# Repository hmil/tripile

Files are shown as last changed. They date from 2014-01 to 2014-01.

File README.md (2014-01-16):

# Trieur de piles 

Ce repo contient tout le nécessaire à la réalisation du trieur de pile vu au concours Innovez 
(si vous ne savez pas de quoi il s'agit, vous vous êtes probablement perdu sur github).
Vous trouverez un assemblage solidworks de la machine, une sketch fritzing et une sketch arduino.
J'ai créé ce repo à partir du dossier que j'ai retrouvé sur mon disque suite à des demandes. Si vous assemblez
tout comme montré, il se peut que celà ne marche pas car j'ai du effectuer des modifications sur la partie électronique.

tl;dr: Le code arduino fonctionne, l'assemblage solidworks est fidèle mais le circuit électronique est probablement buggé.

Enjoy

(c) Hadrien Milano 2013,
La license [beerware](http://fr.wikipedia.org/wiki/Beerware) s'applique à tout le repo.

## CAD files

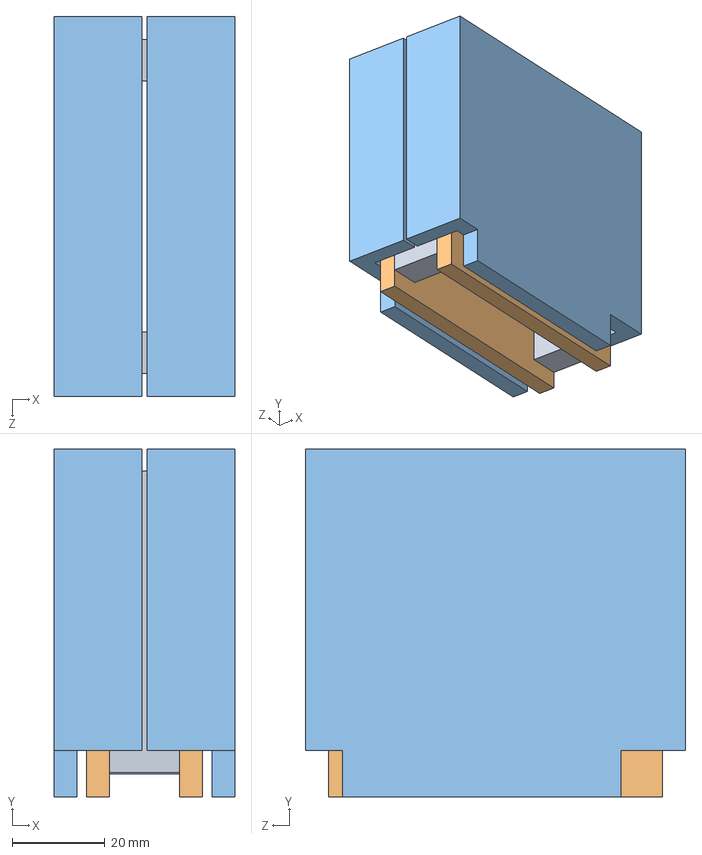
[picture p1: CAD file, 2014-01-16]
solidworks/reserv+recept_rangement.SLDASM
39.0 x 75.0 x 82.0 mm
entretoise x 2
paroi_reservoir x 2
receptacle x 2

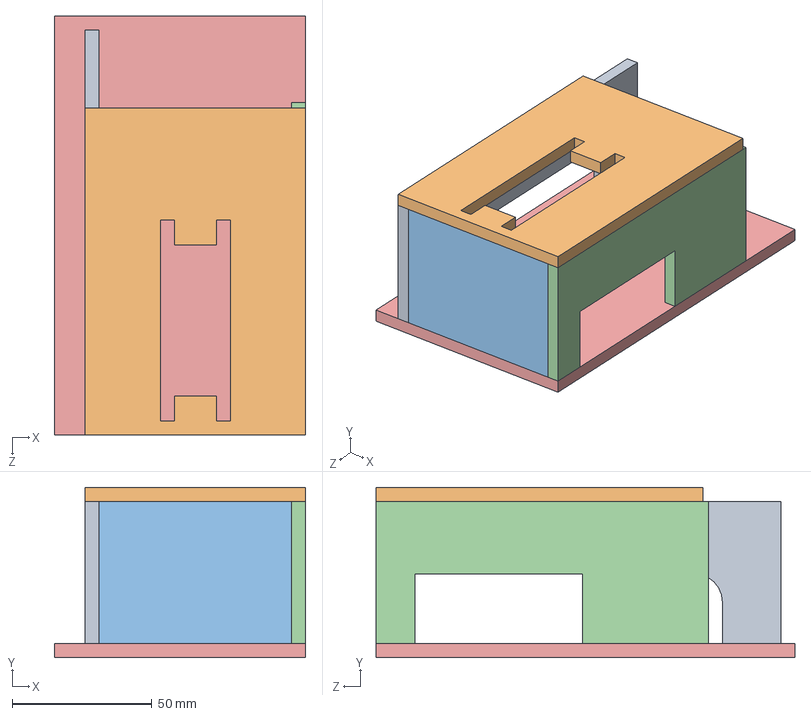
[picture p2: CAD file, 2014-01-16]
solidworks/carter.SLDASM
90.0 x 61.0 x 150.0 mm
top
front
side2
side
base

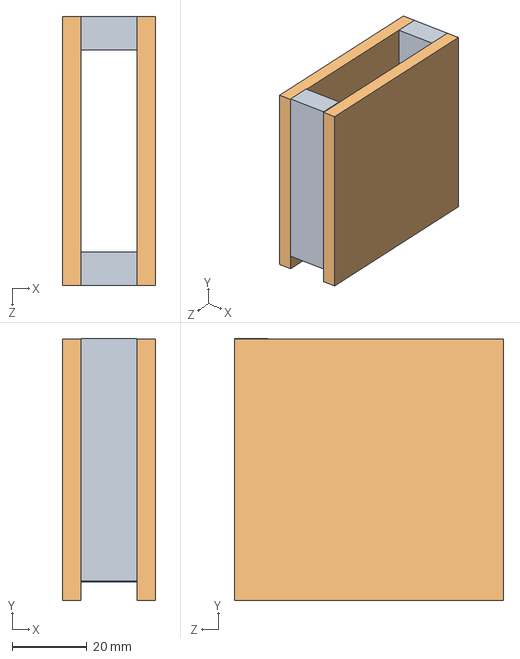
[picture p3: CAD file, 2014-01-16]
solidworks/reservoir.SLDASM
25.0 x 70.2 x 72.0 mm
entretoise x 2
paroi_reservoir x 2

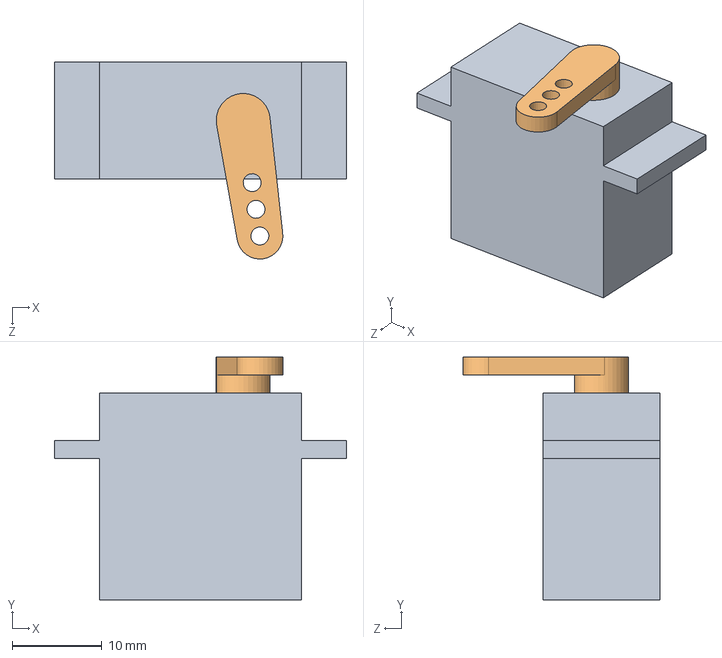
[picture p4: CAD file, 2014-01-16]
solidworks/servo2.SLDASM
32.5 x 27.0 x 21.9 mm
servo2
bras_servo2

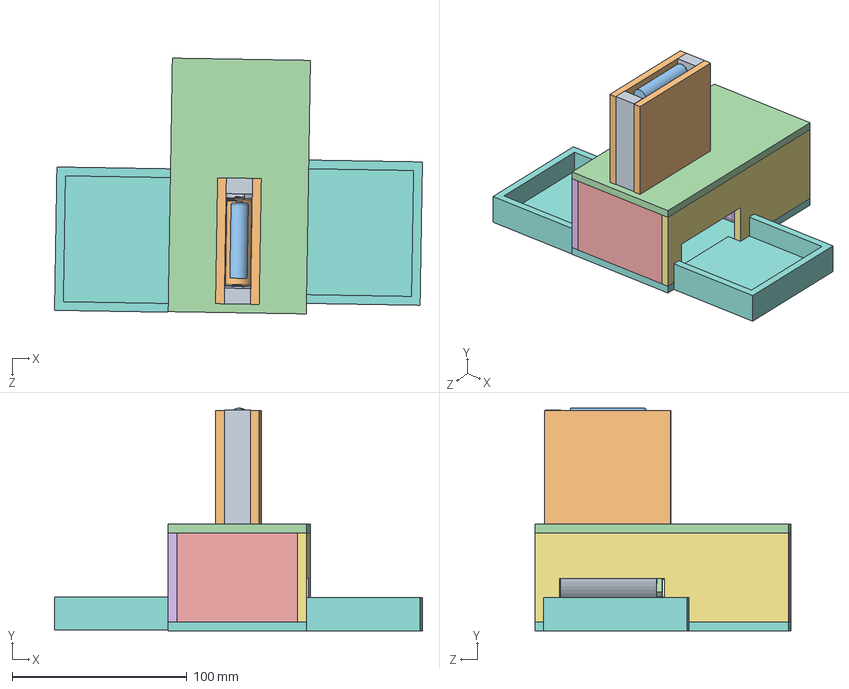
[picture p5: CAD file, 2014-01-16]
solidworks/tripile+2ke.SLDASM
210.4 x 127.4 x 146.3 mm
distributeur
AA Battery x 3
AAA Battery x 4
top
front x 2
side2
side
base
entretoise x 2
paroi_reservoir x 2
support_distrib x 2
servo
support_servo
Battery 9V
traverse x 2
receptacle x 2
servo2
bras_servo2
capot

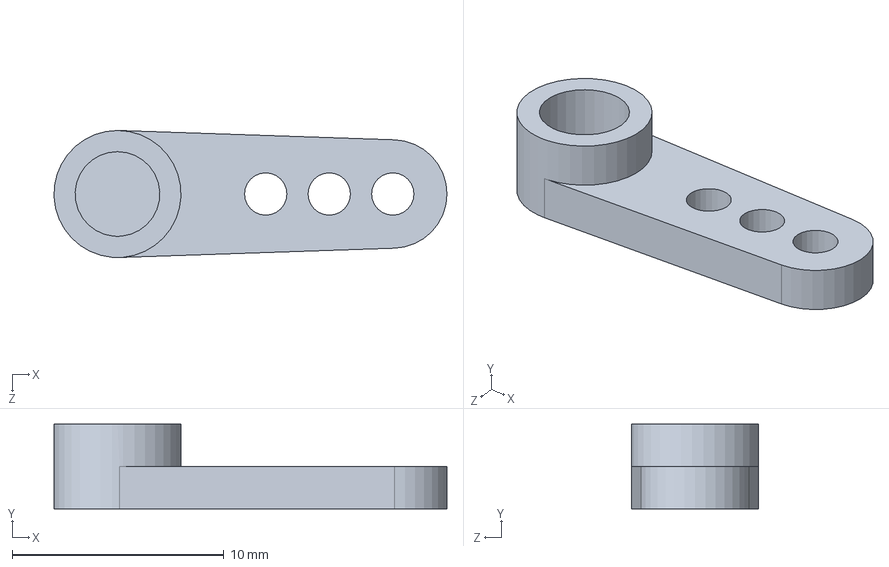
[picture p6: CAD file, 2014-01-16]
solidworks/bras_servo2.SLDPRT
18.6 x 4.00 x 6.00 mm

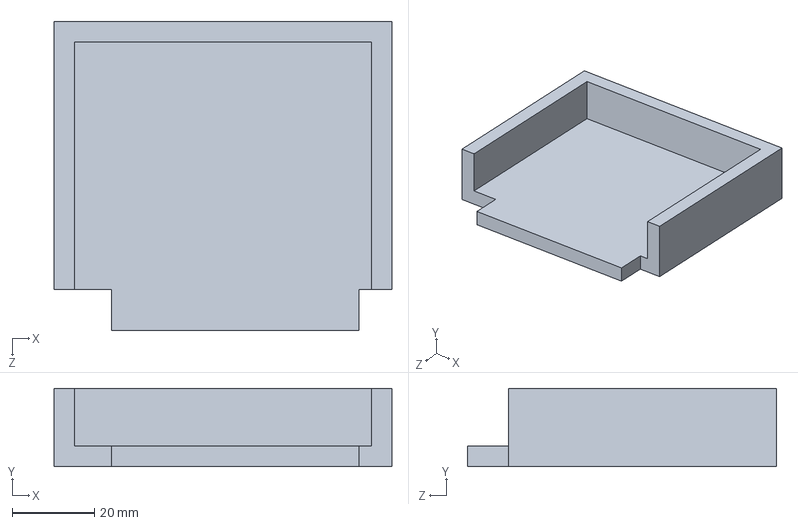
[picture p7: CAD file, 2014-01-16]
solidworks/receptacle.SLDPRT
82.0 x 19.0 x 75.0 mm

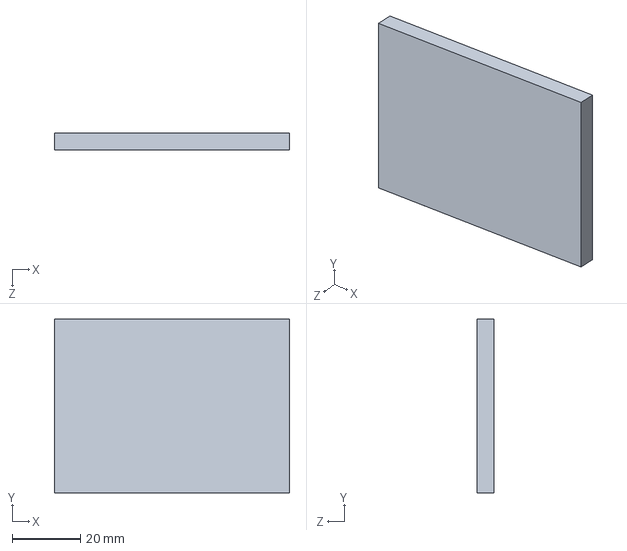
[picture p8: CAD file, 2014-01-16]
solidworks/front.SLDPRT
69.0 x 51.0 x 5.00 mm

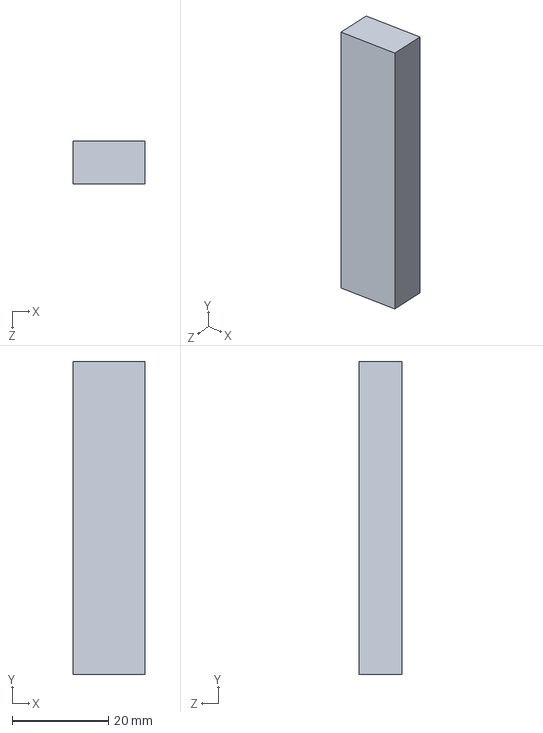
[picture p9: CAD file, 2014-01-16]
solidworks/entretoise.SLDPRT
15.0 x 65.0 x 9.00 mm

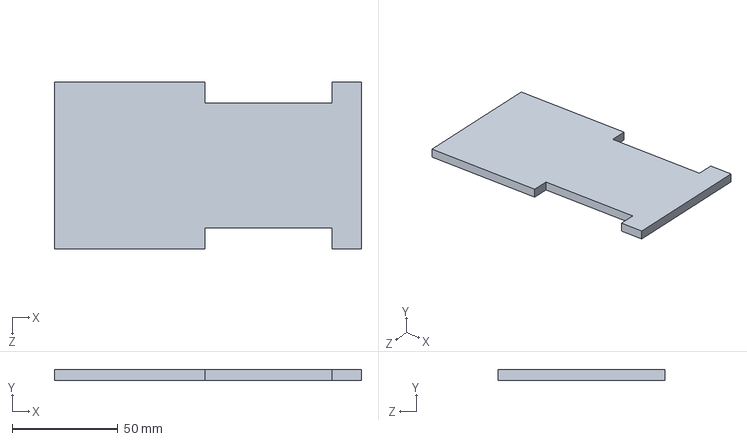
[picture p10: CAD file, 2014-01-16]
solidworks/base.SLDPRT
145.0 x 5.00 x 79.0 mm

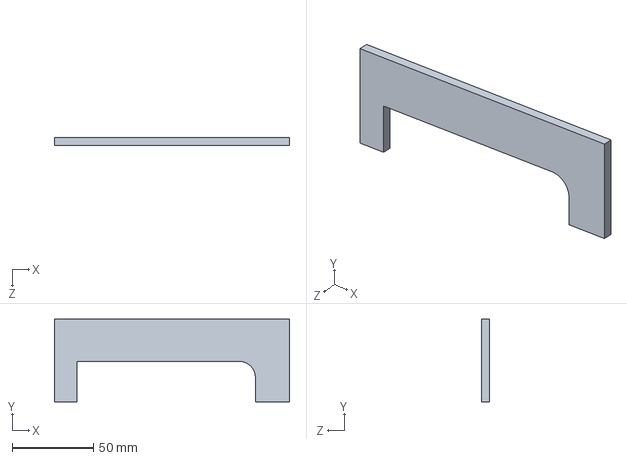
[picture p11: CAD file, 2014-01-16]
solidworks/side2.SLDPRT
145.0 x 51.0 x 5.00 mm

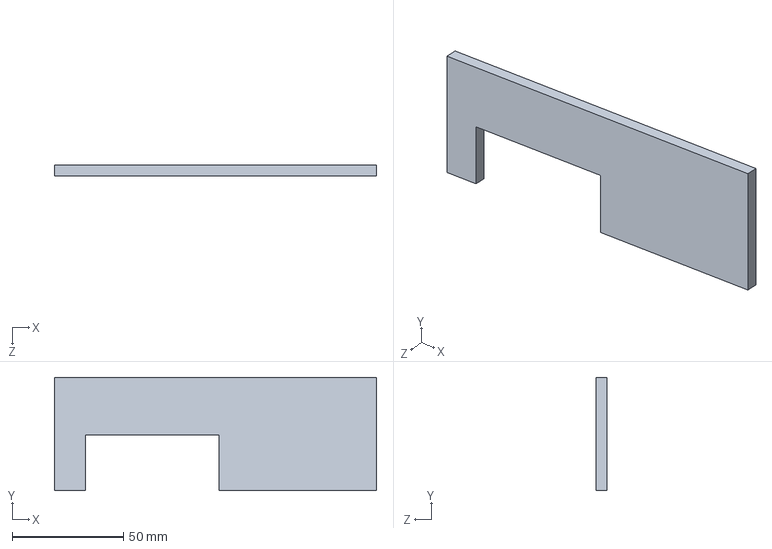
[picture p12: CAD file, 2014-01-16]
solidworks/side.SLDPRT
145.0 x 51.0 x 5.00 mm

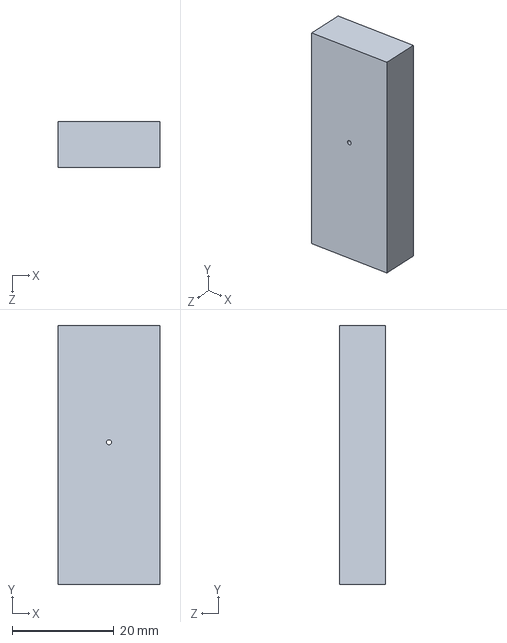
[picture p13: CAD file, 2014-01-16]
solidworks/support_distrib.SLDPRT
20.0 x 51.0 x 9.00 mm

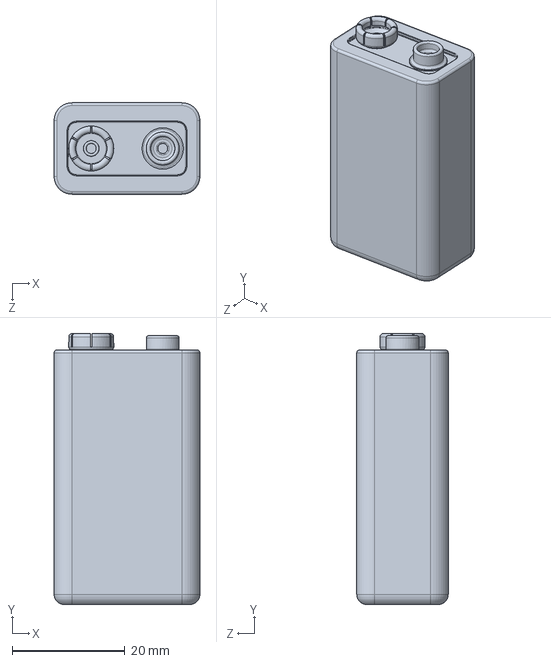
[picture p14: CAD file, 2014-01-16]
solidworks/Battery 9V.SLDPRT
25.9 x 48.1 x 16.3 mm

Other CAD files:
solidworks/support_servo.SLDPRT
solidworks/AA Battery.SLDPRT
solidworks/AAA Battery.SLDPRT
solidworks/renfort.SLDPRT
solidworks/capot.SLDPRT
solidworks/carter.SLDPRT
solidworks/distributeur.SLDPRT
solidworks/paroi_reservoir.SLDPRT
solidworks/servo.SLDPRT
solidworks/servo2.SLDPRT
solidworks/top.SLDPRT
solidworks/traverse.SLDPRT

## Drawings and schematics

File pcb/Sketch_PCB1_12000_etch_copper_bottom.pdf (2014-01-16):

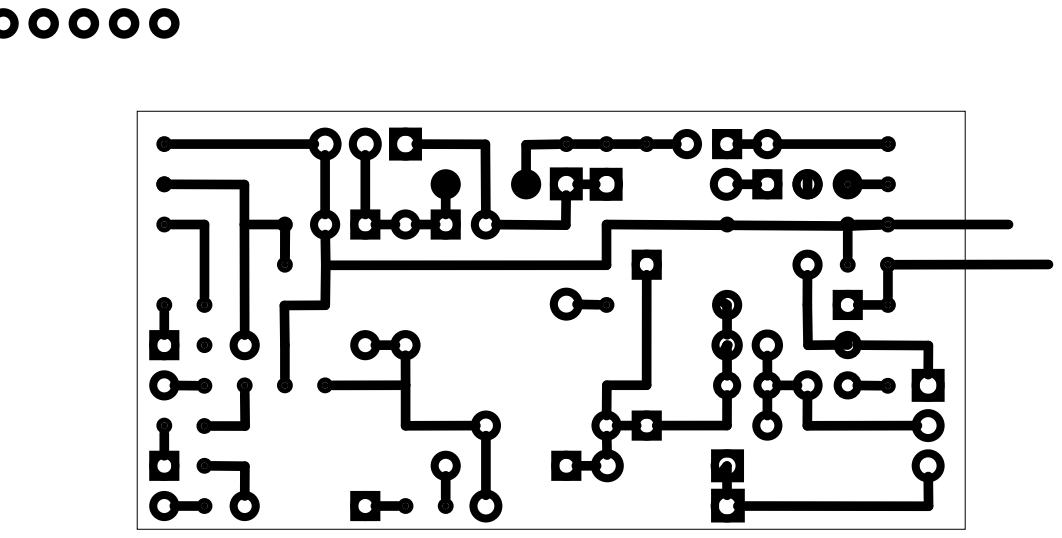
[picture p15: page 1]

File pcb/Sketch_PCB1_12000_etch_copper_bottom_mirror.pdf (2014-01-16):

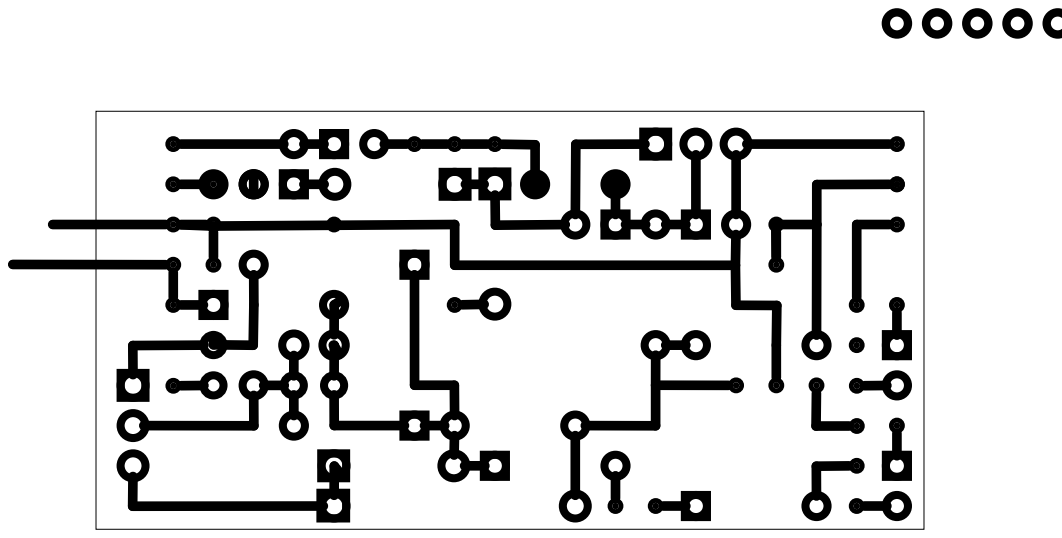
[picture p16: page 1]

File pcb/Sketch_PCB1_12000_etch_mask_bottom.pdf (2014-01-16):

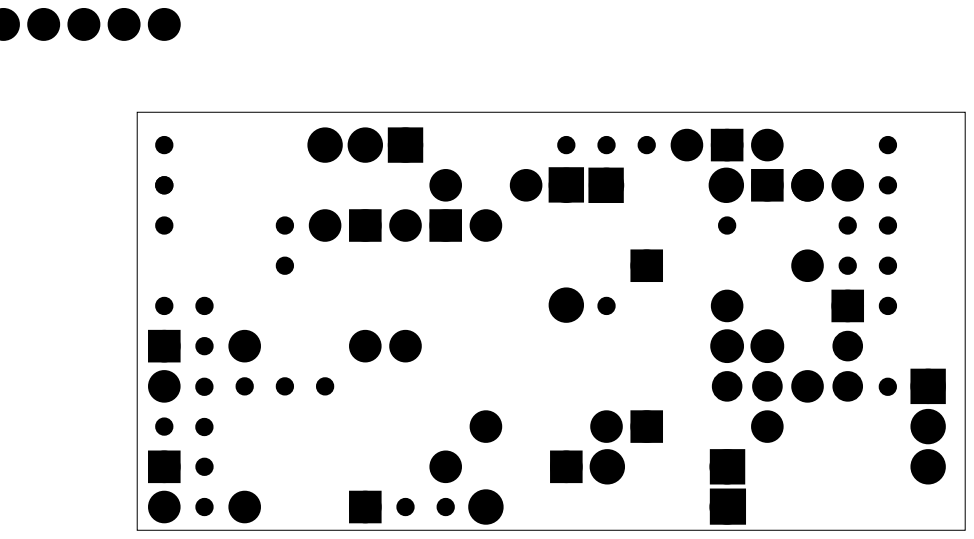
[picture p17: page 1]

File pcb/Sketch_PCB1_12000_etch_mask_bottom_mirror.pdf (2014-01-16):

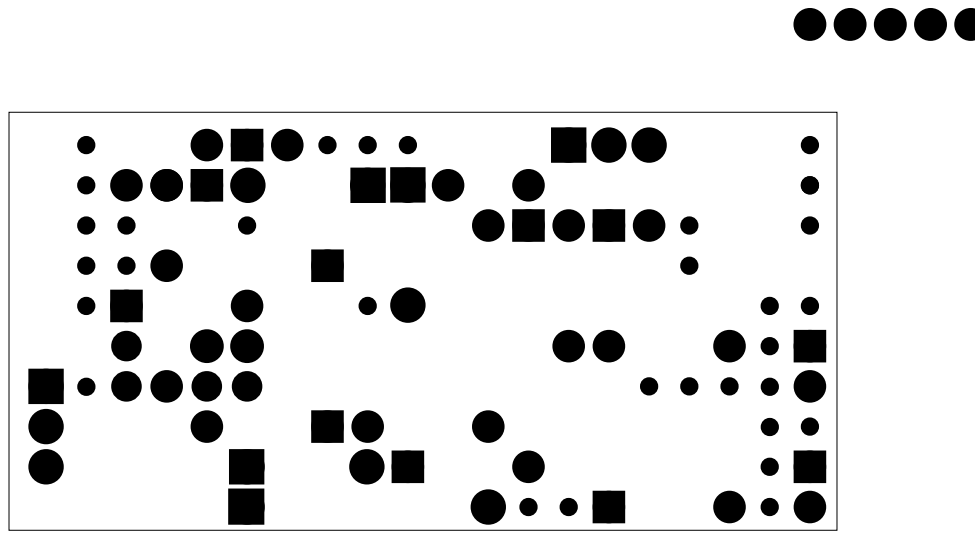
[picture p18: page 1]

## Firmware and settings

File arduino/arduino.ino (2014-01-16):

#include <robopoly.h>
#include <Servo.h>

#define LOW_BATT_VAL            720

#define SONDE_RETRACTED         67
#define SONDE_DEPLOYED_BIG      140
#define SONDE_DEPLOYED_LITTLE   170

#define DISTRIB_MIDDLE          78
#define DISTRIB_LOW             5
#define DISTRIB_HIGH            180

#define DISTRIBUTION_DELAY      700
#define SONDE_DEPLOYMENT_DELAY  500
#define NOISE_THRESHOLD         50
#define PILE_MINIMAL_TENSION    220

//En dessous de cette valeur, l'objet testé est considéré comme un accu
#define ACCU_THRESHOLD          270
/*  Ces valeurs sont comparées aux tensions mesurées en décharge
  hypothèses : 
  - accu : U = 1.2V, r ~= 0.02ohm
  - pile : U = 1.5V, r ~= 1ohm
  
  avec une certaine marge de manoeuvre car ces résultats théoriques 
  peuvent facilement faire passer une pile chargée pour déchargée
  */
#define PILE_LOADED             100
#define ACCU_LOADED             90


//Macro permettant de finaliser un test  
#define FINISH_TEST(success)       \
  servoOneShot(sonde, SONDE_RETRACTED, SONDE_DEPLOYMENT_DELAY);    \
  *result = success;               \
  return true; 

int pilePin = 0;
int batteryPin = 1;

int cptPin = 15;

unsigned char sonde = 5;

unsigned char distrib = 7;

int triggerPin = 13;

int buttonPin = 30;
bool buttonDown = false;

int lowBattLed = 26;
int okLed = 28;
int nokLed = 27;

void checkBattery(){
  int level = analogRead(batteryPin);
  if(level < LOW_BATT_VAL){
    digitalWrite(lowBattLed, true);
  }
}

//Deplace le servo a la position voulue puis le déconnecte (fonction bloquante)
void servoOneShot(unsigned char id, unsigned char angle, int time){
  setServo(id, angle);
  delay(time);
  unsetServo(id);
}

void setup(){
  Serial.begin(9600);
  pinMode(pilePin, INPUT);
  pinMode(batteryPin, INPUT);
  pinMode(triggerPin, OUTPUT);
  pinMode(buttonPin, INPUT);
  pinMode(cptPin, INPUT);
  digitalWrite(triggerPin, LOW);
  
  pinMode(okLed, OUTPUT);
  pinMode(nokLed, OUTPUT);
  pinMode(lowBattLed, OUTPUT);
  
  digitalWrite(okLed, LOW);
  digitalWrite(nokLed, LOW);
  digitalWrite(lowBattLed, LOW);

  servoOneShot(sonde, SONDE_RETRACTED, SONDE_DEPLOYMENT_DELAY);

  servoOneShot(distrib, DISTRIB_MIDDLE, DISTRIBUTION_DELAY);
  
  //On attend que les servo aient fini de tourner pour faire le test de batterie
  delay(200);
  checkBattery();
}

void onPileOk(){
  Serial.println("Pile chargée");
  digitalWrite(okLed, HIGH);
  servoOneShot(distrib, DISTRIB_HIGH, DISTRIBUTION_DELAY);
  servoOneShot(distrib, DISTRIB_MIDDLE, DISTRIBUTION_DELAY);
  digitalWrite(okLed, LOW);
}

void onPileNok(){
  Serial.println("Pile déchargée");
  digitalWrite(nokLed, HIGH);
  servoOneShot(distrib, DISTRIB_LOW, DISTRIBUTION_DELAY);
  servoOneShot(distrib, DISTRIB_MIDDLE, DISTRIBUTION_DELAY);
  digitalWrite(nokLed, LOW);
}

bool makeTest(int sondeValue, bool *result){
  int initialValue = 0,
      chargeValue = 0;
  
  servoOneShot(sonde, sondeValue, SONDE_DEPLOYMENT_DELAY);
  
  initialValue = analogRead(pilePin);
  
  
  Serial.print("Premiere valeur : ");
  //Serial.println(initialValue);
  //Si on ne capte rien, le test est un échec
  if(initialValue < NOISE_THRESHOLD){
    Serial.println("Valeur trop basse.");

    return false;
  }
  
  //ON a détecté quelque chose mais c'est trop faible
  if(initialValue < PILE_MINIMAL_TENSION){
    Serial.println("Pile déchargée détectée");
    FINISH_TEST(false);
  }
  else{
    
    bool isAccu = (initialValue < ACCU_THRESHOLD);
    //On a une mesure valide, on effectue le test de charge
    digitalWrite(triggerPin, true);
    delayMicroseconds(20);
    chargeValue = analogRead(pilePin);
    digitalWrite(triggerPin, false);
    
    Serial.print("Pile détectée,\ntension en décharge :");
    //Serial.println(chargeValue);
    
    //La tension en décharge est trop faible, test négatif
    if(isAccu && (chargeValue < ACCU_LOADED) || !isAccu && (chargeValue < PILE_LOADED)){
      Serial.println("pile déchargée");
      FINISH_TEST(false);
    }
    //Sinon, le test est positif
    else{
      Serial.println("Pile chargée");
      FINISH_TEST(true);
    }
  }
  
  //Il est impossible d'arriver ici mais au cas ou...
  servoOneShot(sonde, SONDE_RETRACTED, SONDE_DEPLOYMENT_DELAY);
  return false;
}

bool test(){
  bool testResult;
  Serial.println("--- Début des tests ---");
  if(makeTest(SONDE_DEPLOYED_BIG, &testResult)){
    return testResult;
  }
  else if(makeTest(SONDE_DEPLOYED_LITTLE, &testResult)){
    return testResult;
  }
  servoOneShot(sonde, SONDE_RETRACTED, SONDE_DEPLOYMENT_DELAY);
  return false;
}

void start(){
  do{
    if(test()){
      onPileOk();
    }
    else{
      onPileNok();
    }
    //On pousse la pile vers le capteur
    servoOneShot(sonde, SONDE_DEPLOYED_BIG, SONDE_DEPLOYMENT_DELAY);
    
    buttonDown = digitalRead(buttonPin);
  }while(digitalRead(cptPin) && !buttonDown);
  
  servoOneShot(sonde, SONDE_RETRACTED, SONDE_DEPLOYMENT_DELAY);
}

void loop(){
  
  bool buttonState = digitalRead(buttonPin);
  if(digitalRead(buttonPin) && !buttonDown){
    start();
  }
  else if(!buttonState){
    //Evite de relancer un cycle quand l'utilsateur a annulé
    buttonDown = false;
  }
  
  delay(10);
}
